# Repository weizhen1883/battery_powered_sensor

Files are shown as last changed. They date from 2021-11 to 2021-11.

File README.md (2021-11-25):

# Battery Powered Sensor
This project designed a battery powered IMU sensor. This sensor require to use a IMU, LSM6DSMTR, made by ST. This sensor require to be powered by battery and have a pushbutton to turn on and off.

## Table of Contents
1. [Hardware](hardware/README.md)
2. [Firmware](firmware/README.md)
3. [Parts Specifications](#parts-specifications)
4. [Operational Specifications](#operational-specifications)

## Parts Specifications
1. MCU
 - Chip Number: nRF52832
 - Module Number: PTR5618
2. Button
 - Single pole, momentary, normally open type
3. IMU
 - Part Number: [LSM6DSMTR](https://www.st.com/content/ccc/resource/technical/document/datasheet/76/27/cf/88/c5/03/42/6b/DM00218116.pdf/files/DM00218116.pdf/jcr:content/translations/en.DM002181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)
4. Battery:
 - Part number: [LP501218JH](https://www.jauch.com/downloadfile/5bf52a0e7827c7c5e9e1dbf47ce24c136/60mah_-_lp501218jh_1s1p_2_wire_50mm.pdf)

## Operational Specifications
1. Firmware requirements
 - Configure all that is required to communicate via SPI with the IMU
 - Configure the IMU
 - Sample the IMU at 833 hz, the sampled data can be discarded in this example.
 - ** NOTE: Keep the firmware simple, this is an example project and will not need to be maintained in the future.
2. IMU Configuration
 - SPI communication mode
 - Both accelerometer and gyro data should be sampled
 - Accelerometer range should be set to +-16g
 - Gyro range should be set to +-2000 dps
 - All other settings/features can be disabled or configured as desired/needed.
3. Button Operation
 - From the ‘OFF’ state: Press the button once to switch the device to the ‘ON’ state. The duration of the press is not important or specified.
 - From the ‘ON’ state: Press and hold the button for >500ms to switch the device to the ‘OFF’ state.
4. Power consumption
 - In the ‘OFF’ state, the device should not significantly drain the battery in 1 year. Design should minimize the power off current consumption.
 - In the ‘ON’ state, power consumption is not limited.

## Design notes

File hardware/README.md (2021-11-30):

# Battery Powered Sensor Hardware

## Table of Contents
1. [Requirements](#requirements)
2. [Usage](#usage)
3. [Releases](#releases)
4. [Versions](#versions)
5. [Licenses](#licenses)

## Requirements
1. [eagle_pcb_library](https://github.com/weizhen1883/eaglePCBLibrary.git)

## Usage
#### generate PCB files
1. open the battery_powered_sensor.brd file
2. click "CMA Processor"
3. load the CAM.cam file, and click "process job"
4. the PCB files are generated in "outputs" folder

## Releases
#### Release-1
- Version 1.0.0

## Versions
#### Version 1.0.0
- circuits to support nRF52832 module
- boost converter to support 3.3V
- single pushbutton for on/off and normal control
- circuits for IMU, LSM6DSM, in mode1 and using SPI

## Licenses

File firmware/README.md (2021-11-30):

# Battery Powered Sensor Firmware

## Table of Contents
1. [Requirements](#requirements)
2. [Usage](#usage)
3. [Releases](#releases)
4. [Versions](#versions)
5. [Licenses](#licenses)

## Requirements
1. nRF5_SDK v17.1.0

## Usage

## Releases
#### Release-1
- version 1.0.0

## Versions
#### Version 1.0.0
- set sampling timer for 833Hz
- configure for spi
- settings for IMU
- read data from IMU

## Licenses
> Copyright (c) 2015 - 2021, Nordic Semiconductor ASA
>
> All rights reserved.
>
> Redistribution and use in source and binary forms, with or without modification,
> are permitted provided that the following conditions are met:
>
> 1. Redistributions of source code must retain the above copyright notice, this
>    list of conditions and the following disclaimer.
>
> 2. Redistributions in binary form, except as embedded into a Nordic
>    Semiconductor ASA integrated circuit in a product or a software update for
>    such product, must reproduce the above copyright notice, this list of
>    conditions and the following disclaimer in the documentation and/or other
>    materials provided with the distribution.
>
> 3. Neither the name of Nordic Semiconductor ASA nor the names of its
>    contributors may be used to endorse or promote products derived from this
>    software without specific prior written permission.
>
> 4. This software, with or without modification, must only be used with a
>    Nordic Semiconductor ASA integrated circuit.
>
> 5. Any software provided in binary form under this license must not be reverse
>    engineered, decompiled, modified and/or disassembled.
>
> THIS SOFTWARE IS PROVIDED BY NORDIC SEMICONDUCTOR ASA "AS IS" AND ANY EXPRESS
> OR IMPLIED WARRANTIES, INCLUDING, BUT NOT LIMITED TO, THE IMPLIED WARRANTIES
> OF MERCHANTABILITY, NONINFRINGEMENT, AND FITNESS FOR A PARTICULAR PURPOSE ARE
> DISCLAIMED. IN NO EVENT SHALL NORDIC SEMICONDUCTOR ASA OR CONTRIBUTORS BE
> LIABLE FOR ANY DIRECT, INDIRECT, INCIDENTAL, SPECIAL, EXEMPLARY, OR
> CONSEQUENTIAL DAMAGES (INCLUDING, BUT NOT LIMITED TO, PROCUREMENT OF SUBSTITUTE
> GOODS OR SERVICES; LOSS OF USE, DATA, OR PROFITS; OR BUSINESS INTERRUPTION)
> HOWEVER CAUSED AND ON ANY THEORY OF LIABILITY, WHETHER IN CONTRACT, STRICT
> LIABILITY, OR TORT (INCLUDING NEGLIGENCE OR OTHERWISE) ARISING IN ANY WAY OUT
> OF THE USE OF THIS SOFTWARE, EVEN IF ADVISED OF THE POSSIBILITY OF SUCH DAMAGE.

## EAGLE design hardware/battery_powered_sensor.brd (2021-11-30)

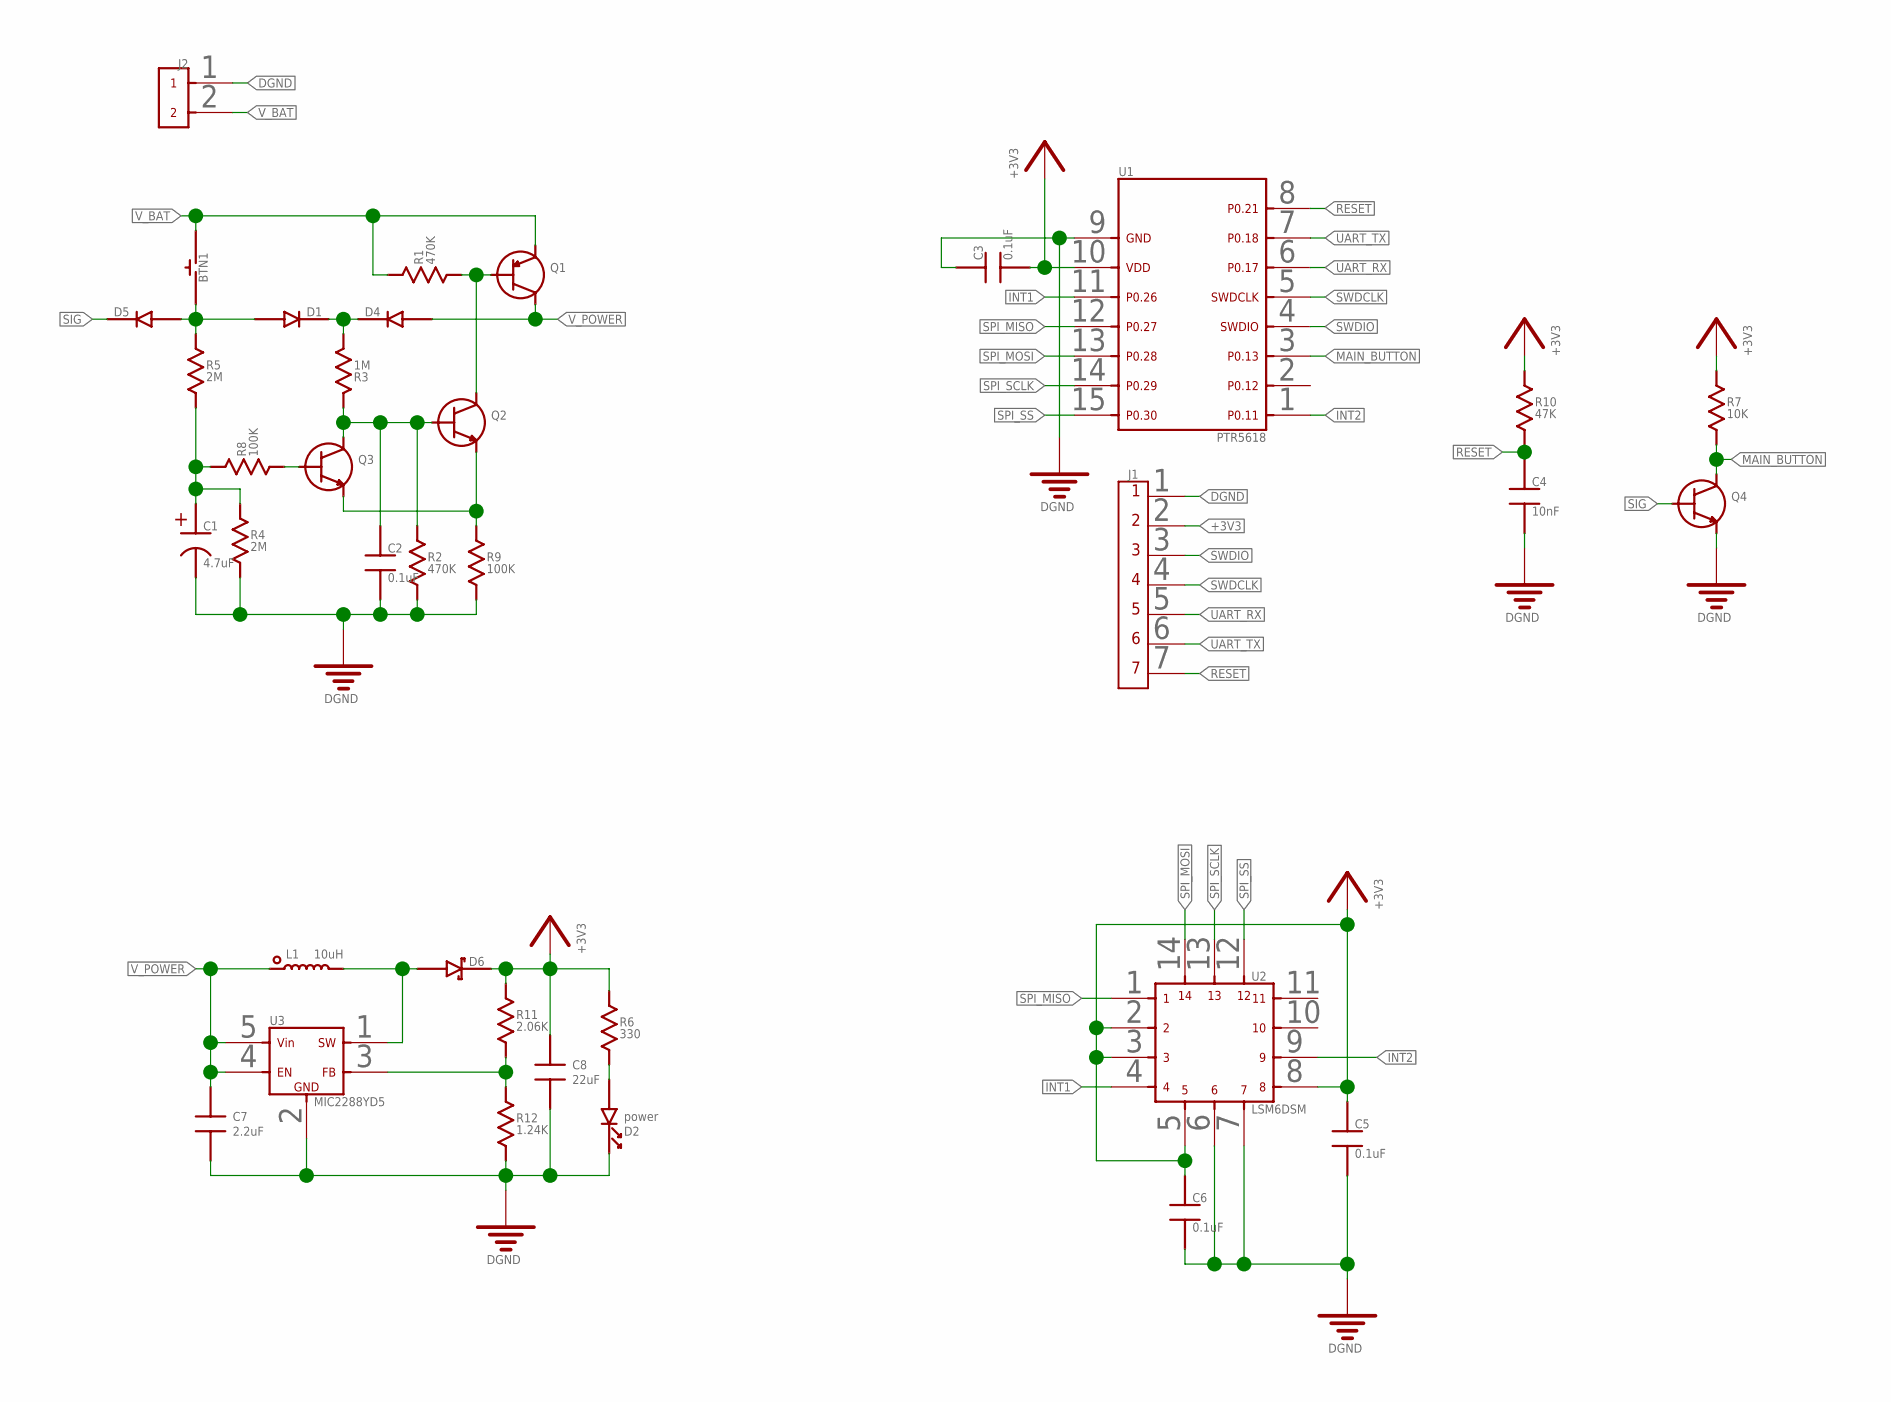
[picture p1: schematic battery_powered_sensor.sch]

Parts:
BTN1: BTN_NORMAL_OFF_6_3.5_SMD; BTN_6_3.5_SMD
C1: 4.7uF; CAP_530_530
C2, C3, C5, C6: 0.1uF; 0805
C4: 10nF; 0805
C7: 2.2uF; 0805
C8: 22uF; 0805
D1, D4, D5: DIODE0805; 0805DIODE
D2: power; 0805DIODE
D6: SCHOTTKY_DIODE_0805; 0805DIODE
J1: 7PIN_HEADER_PITCH2.54MM_TH
J2: 2PIN_HEADER_PITCH2.54MM_TH
L1: 10uH; 1008
Q1: MMBT4403; SOT_23_3
Q2, Q3, Q4: BC846; SOT_23_3
R1, R2: 470K; 0805
R3: 1M; 0805
R4, R5: 2M; 0805
R6: 330; 0805
R7: 10K; 0805
R8, R9: 100K; 0805
R10: 47K; 0805
R11: 2.06K; 0805
R12: 1.24K; 0805
U1: PTR5618
U2: LSM6DSM; LGA-14L
U3: MIC2288YD5; SOT-23-5

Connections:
+3V3: C3.2, C5.1, C6.1, C8.1, D6.1, J1.2, R6.1, R7.1, R10.1, R11.1, U1.10, U2.2, U2.3, U2.5, U2.8
DGND: C1.2, C2.2, C3.1, C4.2, C5.2, C6.2, C7.2, C8.2, D2.1 (K), J1.1, J2.1, Q4.3 (E), R2.2, R4.2, R9.2, R12.2, U1.9, U2.6, U2.7, U3.2 (GND)
INT1: U1.11, U2.4
INT2: U1.1, U2.9
MAIN_BUTTON: Q4.2 (C), R7.2, U1.3
unnamed: D1.1, D4.1, R3.2
unnamed: Q1.1 (B), Q2.2 (C), R1.2
unnamed: Q2.3 (E), Q3.3 (E), R9.1
unnamed: C2.1, Q2.1 (B), Q3.2 (C), R2.1, R3.1
unnamed: D2.2 (A), R6.2
unnamed: C1.1, R4.1, R5.2, R8.1
unnamed: Q3.1 (B), R8.2
unnamed: BTN1.1, D1.2, D5.2, R5.1
unnamed: R11.2, R12.1, U3.3 (FB)
unnamed: D6.2, L1.2, U3.1 (SW)
RESET: C4.1, J1.7, R10.2, U1.8
SIG: D5.1, Q4.1 (B)
SPI_MISO: U1.12, U2.1
SPI_MOSI: U1.13, U2.14
SPI_SCLK: U1.14, U2.13
SPI_SS: U1.15, U2.12
SWDCLK: J1.4, U1.5
SWDIO: J1.3, U1.4
UART_RX: J1.5, U1.6
UART_TX: J1.6, U1.7
V_BAT: BTN1.2, J2.2, Q1.3 (E), R1.1
V_POWER: C7.1, D4.2, L1.1, Q1.2 (C), U3.4 (EN), U3.5 (VIN)

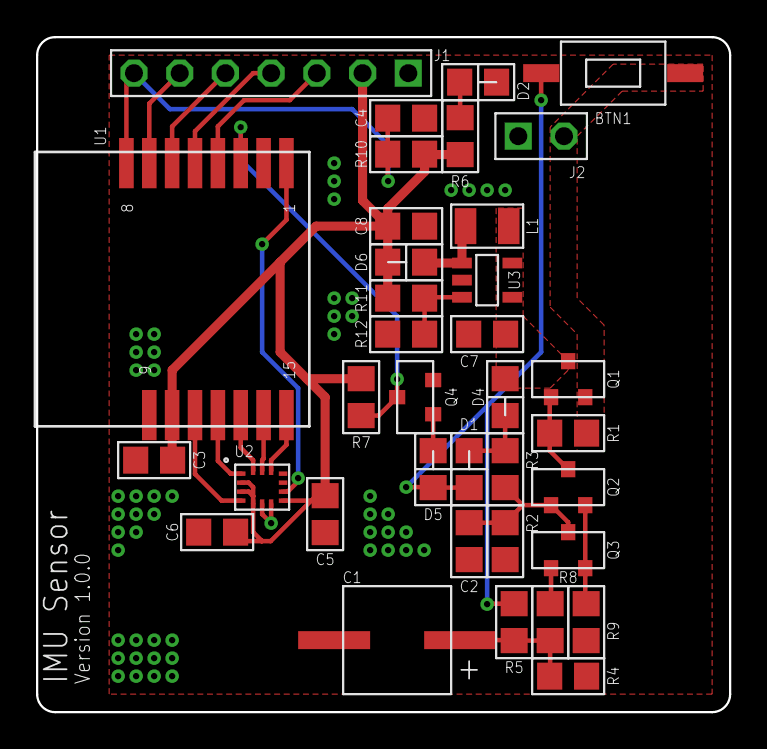
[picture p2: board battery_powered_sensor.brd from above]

Board: 2 copper layers, 38.5 x 37.5 mm, 36 parts (0 on the bottom side), 27 nets.

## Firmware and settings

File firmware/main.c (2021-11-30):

#include <string.h>
#include "nrf.h"
#include "nrf_timer.h"
#include "nrf_gpio.h"
#include "nrf_delay.h"
#include "nrf_log.h"
#include "nrf_log_ctrl.h"
#include "nrf_log_default_backends.h"
#include "nrf_drv_spi.h"
#include "app_util_platform.h"
#include "app_error.h"

#define PIN_SPI_SS          30
#define PIN_SPI_MISO        27
#define PIN_SPI_MOSI        28
#define PIN_SPI_SCK         29

#define LSM6DSM_WRITE_MASK          0x7F
#define LSM6DSM_READ_MASK           0x80

/* ----- LSM6DSM Register Addresses ---- */
#define LSM6DSM_REG_CTRL1_XL    0x10
#define LSM6DSM_REG_CTRL2_G     0x11
#define LSM6DSM_REG_CTRL3_C     0x12
#define LSM6DSM_REG_CTRL4_C     0x13
#define LSM6DSM_REG_CTRL5_C     0x14
#define LSM6DSM_REG_CTRL6_C     0x15
#define LSM6DSM_REG_CTRL7_G     0x16
#define LSM6DSM_REG_CTRL8_XL    0x17
#define LSM6DSM_REG_CTRL9_XL    0x18
#define LSM6DSM_REG_CTRL10_C    0x19

#define LSM6DSM_REG_OUT_TEMP_L  0x20
#define LSM6DSM_REG_OUT_TEMP_H  0x21
#define LSM6DSM_REG_OUTX_L_G    0x22
#define LSM6DSM_REG_OUTX_H_G    0x23
#define LSM6DSM_REG_OUTY_L_G    0x24
#define LSM6DSM_REG_OUTY_H_G    0x25
#define LSM6DSM_REG_OUTZ_L_G    0x26
#define LSM6DSM_REG_OUTZ_H_G    0x27
#define LSM6DSM_REG_OUTX_L_XL   0x28
#define LSM6DSM_REG_OUTX_H_XL   0x29
#define LSM6DSM_REG_OUTY_L_XL   0x2A
#define LSM6DSM_REG_OUTY_H_XL   0x2B
#define LSM6DSM_REG_OUTZ_L_XL   0x2C
#define LSM6DSM_REG_OUTZ_H_XL   0x2D

#define MAX_BUF_LEN     10

#define SPI_INSTANCE  0 /**< SPI instance index. */
static const nrf_drv_spi_t spi = NRF_DRV_SPI_INSTANCE(SPI_INSTANCE);  /**< SPI instance. */
static volatile bool sample_timeout = false;  /**< Flags when sampling timer timeout*/

typedef struct
{
    uint16_t x;
    uint16_t y;
    uint16_t z;
} sensor_data_t;

uint8_t LSM6DSM_write (uint8_t addr, uint8_t * data, uint8_t len)
{
    uint8_t err_code = 0;
    uint8_t tx_buf[MAX_BUF_LEN];
    uint8_t rx_buf[MAX_BUF_LEN];
    memset(tx_buf, 0, MAX_BUF_LEN);
    memset(rx_buf, 0, MAX_BUF_LEN);

    if (MAX_BUF_LEN - 1 < len)
    {
        err_code = 1;
    }
    else
    {
        tx_buf[0] = addr & LSM6DSM_WRITE_MASK;
        memcpy(&tx_buf[1], data, len);

        APP_ERROR_CHECK(nrf_drv_spi_transfer(&spi, tx_buf, len, rx_buf, 0));
    }

    return err_code;
}

uint8_t LSM6DSM_read (uint8_t addr, uint8_t * data, uint8_t len)
{
    uint8_t err_code = 0;
    uint8_t tx_buf[MAX_BUF_LEN];
    uint8_t rx_buf[MAX_BUF_LEN];
    memset(tx_buf, 0, MAX_BUF_LEN);
    memset(rx_buf, 0, MAX_BUF_LEN);

    if (MAX_BUF_LEN - 1 < len)
    {
        err_code = 1;
    }
    else
    {
        tx_buf[0] = addr | LSM6DSM_READ_MASK;

        APP_ERROR_CHECK(nrf_drv_spi_transfer(&spi, tx_buf, 1, rx_buf, len));
    }

    return err_code;
}

void LSM6DSM_settings (void)
{
    // set accelerometer output data rate to 833Hz
    // set accelerometer range to +-16g
    uint8_t accelerometer_settings = 0b01110100; // 0111 for 833hz, 01 for +-16g,
    LSM6DSM_write(LSM6DSM_REG_CTRL1_XL, &accelerometer_settings, 1);

    // set gyroscope output data rate to  833Hz
    // set gyroscope range to +-2000dps
    uint8_t gyroscope_settings = 0b01111100; // 0111 for 833hz, 11 for 2000dps
    LSM6DSM_write(LSM6DSM_REG_CTRL2_G, &gyroscope_settings, 1);

    // disable i2c
    uint8_t control_settings_4 = 0b00000100;
    LSM6DSM_write(LSM6DSM_REG_CTRL4_C, &control_settings_4, 1);
}

uint16_t LSM6DSM_get_output (uint8_t addr)
{
    uint8_t data_buf[2] = { 0x00, 0x00 };
    uint16_t data = 0x0000;
    LSM6DSM_read(addr, &data_buf[0], 2);
    data |= data_buf[1];
    data = (data << 8) | data_buf[0];
    return data;
}

sensor_data_t LSM6DSM_get_gyroscope_output (void)
{
    sensor_data_t data;
    data.x = LSM6DSM_get_output(LSM6DSM_REG_OUTX_L_G);
    data.y = LSM6DSM_get_output(LSM6DSM_REG_OUTY_L_G);
    data.z = LSM6DSM_get_output(LSM6DSM_REG_OUTZ_L_G);
    return data;
}

sensor_data_t LSM6DSM_get_accelerometer_output (void)
{
    sensor_data_t data;
    data.x = LSM6DSM_get_output(LSM6DSM_REG_OUTX_L_XL);
    data.y = LSM6DSM_get_output(LSM6DSM_REG_OUTY_L_XL);
    data.z = LSM6DSM_get_output(LSM6DSM_REG_OUTZ_L_XL);
    return data;
}

void log_info_sensor_data (sensor_data_t data)
{
    uint8_t buf[6] = {
        (data.x >> 8) & 0x00FF, data.x & 0x00FF,
        (data.y >> 8) & 0x00FF, data.y & 0x00FF,
        (data.z >> 8) & 0x00FF, data.z & 0x00FF,
    };
    NRF_LOG_HEXDUMP_INFO(buf, 6);
}

void TIMER2_IRQHandler(void) {
    if ( (NRF_TIMER2->INTENSET & NRF_TIMER_INT_COMPARE0_MASK)
         && (NRF_TIMER2->EVENTS_COMPARE[0] != 0)
       ) {
        NRF_TIMER2->EVENTS_COMPARE[0] = 0;
        NRF_TIMER2->TASKS_CLEAR = 1; /* clear counter */

        sample_timeout = true;
    }
}

int main(void)
{
    sensor_data_t gyroscope_output = { .x = 0, .y = 0, .z = 0 };
    sensor_data_t accelerometer_output = { .x = 0, .y = 0, .z = 0 };

    APP_ERROR_CHECK(NRF_LOG_INIT(NULL));
    NRF_LOG_DEFAULT_BACKENDS_INIT();

    // enable spi
    nrf_drv_spi_config_t spi_config = NRF_DRV_SPI_DEFAULT_CONFIG;
    spi_config.ss_pin   = PIN_SPI_SS;
    spi_config.miso_pin = PIN_SPI_MISO;
    spi_config.mosi_pin = PIN_SPI_MOSI;
    spi_config.sck_pin  = PIN_SPI_SCK;
    APP_ERROR_CHECK(nrf_drv_spi_init(&spi, &spi_config, NULL, NULL));

    // configure sampling timer
    NRF_TIMER2->MODE = NRF_TIMER_MODE_TIMER;
    NRF_TIMER2->TASKS_CLEAR = 1;
    NRF_TIMER2->PRESCALER = 4; /* div by 2^x； = 1 MHz */
    NRF_TIMER2->BITMODE = NRF_TIMER_BIT_WIDTH_16;
    NRF_TIMER2->CC[0] = 833; /* 833 Hz */
    NRF_TIMER2->INTENSET = NRF_TIMER_INT_COMPARE0_MASK;
    NVIC_SetPriority(TIMER2_IRQn, 3);
    NVIC_EnableIRQ(TIMER2_IRQn);

    // set LSM6DSM
    LSM6DSM_settings();

    // enable sampling timer
    sample_timeout = false;
    NRF_TIMER2->TASKS_CLEAR = 1;
	NRF_TIMER2->TASKS_START = 1;

    NRF_LOG_INFO("LSM6DSM sensor started.");

    while (1)
    {
        if (sample_timeout)
        {
            gyroscope_output = LSM6DSM_get_gyroscope_output();
            accelerometer_output = LSM6DSM_get_accelerometer_output();

            NRF_LOG_INFO("Gyroscope: ");
            log_info_sensor_data(gyroscope_output);

            NRF_LOG_INFO("Accelerometer: ");
            log_info_sensor_data(accelerometer_output);

            sample_timeout = false;
        }

        NRF_LOG_FLUSH();
    }
}
